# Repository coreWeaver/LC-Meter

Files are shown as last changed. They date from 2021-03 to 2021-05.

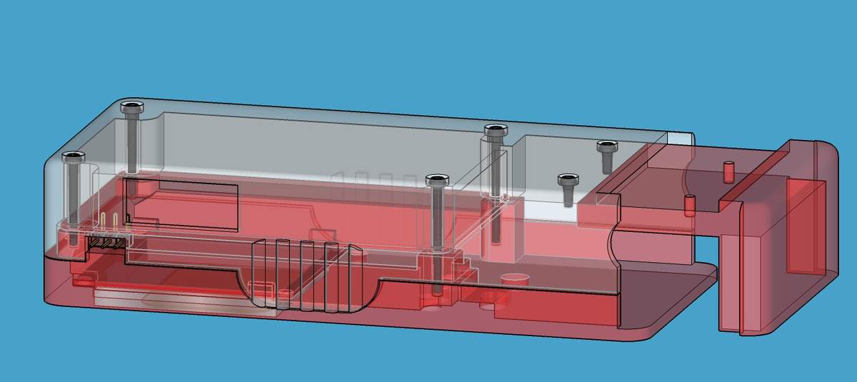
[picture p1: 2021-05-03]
LC Meter v1.0/4a. LC Meter Case - STL (UPDATED)/UPDATED LC Meter Case - transparent.JPG

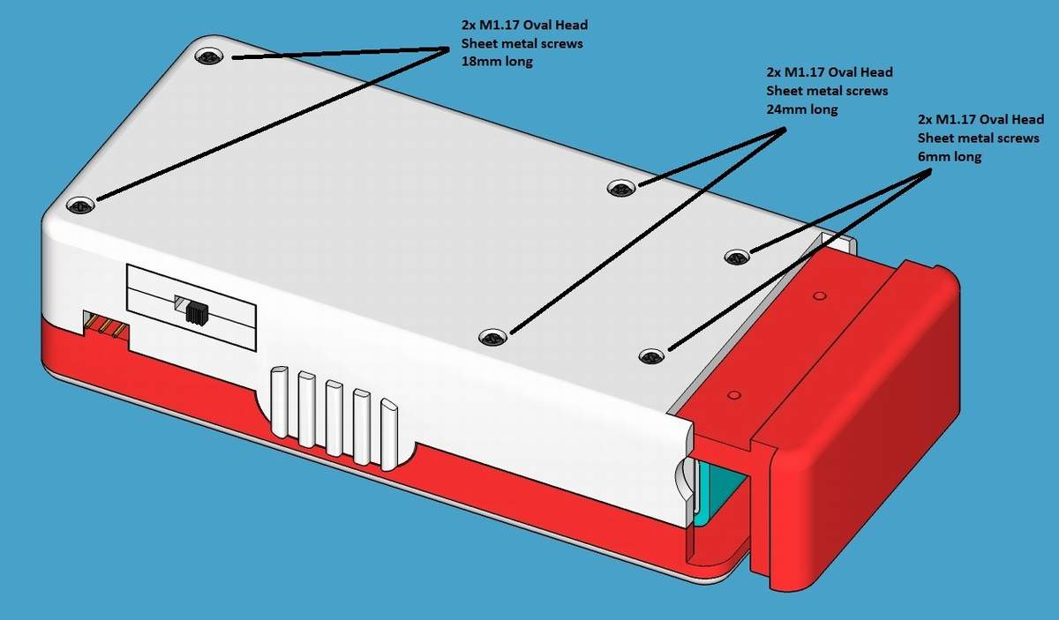
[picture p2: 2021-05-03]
LC Meter v1.0/4a. LC Meter Case - STL (UPDATED)/UPDATED LC Meter Case.JPG

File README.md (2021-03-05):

# LC-Meter
Open Source LC-Meter. All documentation included.

This LC Meter Project is open source. All the documentation both hardware and software is provided without any warranty.
If you build one I would be glad to get a picture of your finished device. 
Subscribe to my Youtube channel and post your comments and questions about this project in the comment section of the series.

The video series is a full tutorial on how it works, how to build it and how to test it.
You can watch it here: https://www.youtube.com/watch?v=KhJiE4gL5T4   (part 1)

About this project:

This design is based on Neil Hecht's idea. It uses an oscillator (LM311) to generate a frequency which can be modified by adding a capacitance or an inductance on the measuring terminals. The frequency is monitored by the microcontroller (ATMEGA328p) and all the math is then performed to extract the value of the added capacitance or inductance.
The value is then adjusted in engineering units and showed on a graphical display.

The PCB is designed using through-hole-terminal components only so it is very easy to solder. There is place for improvements in the schematic, just like I explained in the part 2 of the series (watch here: https://www.youtube.com/watch?v=jytJJjer8_M ).

This project can be improved. A second version would probably include these changes: 

	- make use of a rechargeable Li Ion battery
	- add a usb connector on board 
	- add charging circuitry for the battery
	- add UART - USB translation circuitry on board
	- add a voltage step up to boost the battery voltage to 5V
	- increase the frequency of the AVR

The LC Meter PC application was written in C# and it's very useful when a lot of measurements have to be done. It includes a catalog function for the measured components and a UART logging function for debug purposes.

The firmware for the microcontroller is written in BASCOM. The source files are present also and you can modify them or port to other language if you wish. There is a readme file in the Firmware folder with the FUSES Configuration for the AVR if you decide to use the precompiled firmware.

coreWeaver - ioCONNECTED / Mar. 2021

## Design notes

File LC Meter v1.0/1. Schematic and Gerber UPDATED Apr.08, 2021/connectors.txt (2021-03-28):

LC Meter
coreWeaver/ ioCONNECTED 

Measuring connectors:

Female connectors (for the case) - Spring-mounted socket:

https://www.reichelt.de/de/en/2-0-mm-miniature-socket-red-mbi-1-rt-p11294.html?search=mbi&&r=1

and

https://www.reichelt.de/de/en/miniature-socket--2-mm-black-mbi-1-sw-p11295.html?&trstct=vrt_pdn&nbc=1

The measuring leads:

https://www.reichelt.de/de/en/2-0-mm-mvl-2-50-measuring-lead-red-mvl-2-50-rt-p106057.html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

and

https://www.reichelt.de/de/en/2-0-mm-mvl-2-50-measuring-lead-black-mvl-2-50-sw-p106056.html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

The alligator clips for these leads:

https://www.reichelt.de/de/en/miniature-alligator-clip-2-mm-socket-tin-plated-red-ma-1-s-rt-p130862.html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

and

https://www.reichelt.de/de/en/miniature-alligator-clip-2-mm-socket-tin-plated-black-ma-1-s-sw-p130861.html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

PCB Probes which will fit on these leads:

https://www.reichelt.de/de/en/test-probe--2-mm-red-mps-1-rt-p13109.html?&trstct=pol_14&nbc=1

and

https://www.reichelt.de/de/en/test-probe--2-mm-black-mps-1-sw-p13110.html?&trstct=vrt_pdn&nbc=1

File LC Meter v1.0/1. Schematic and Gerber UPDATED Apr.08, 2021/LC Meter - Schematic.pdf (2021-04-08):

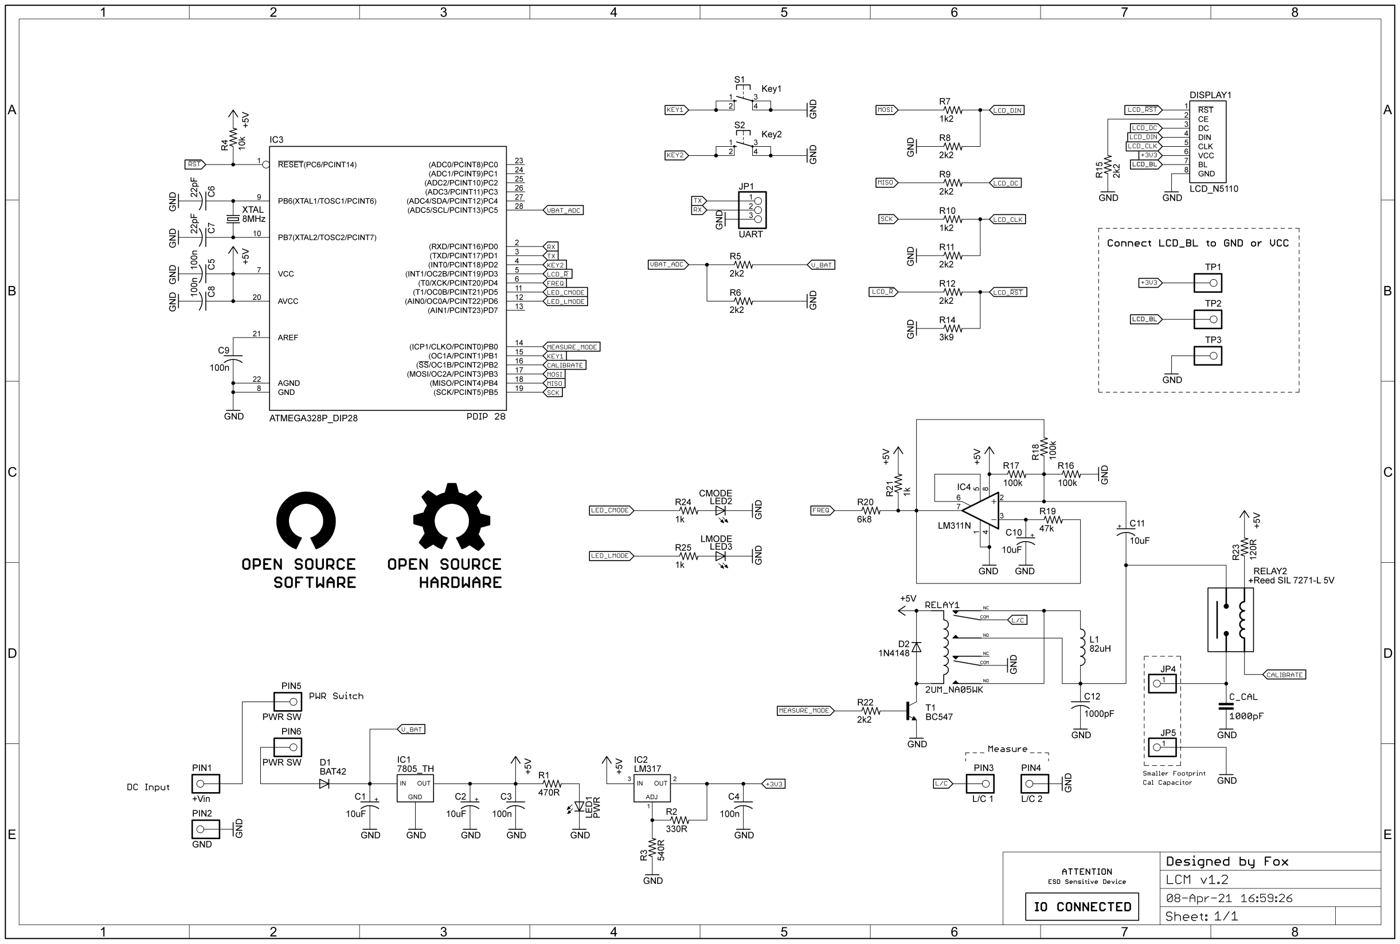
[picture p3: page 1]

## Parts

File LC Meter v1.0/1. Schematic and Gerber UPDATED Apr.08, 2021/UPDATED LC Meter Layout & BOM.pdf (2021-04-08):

LC Meter – Layout (UPDATED: Apr. 08, 2021)

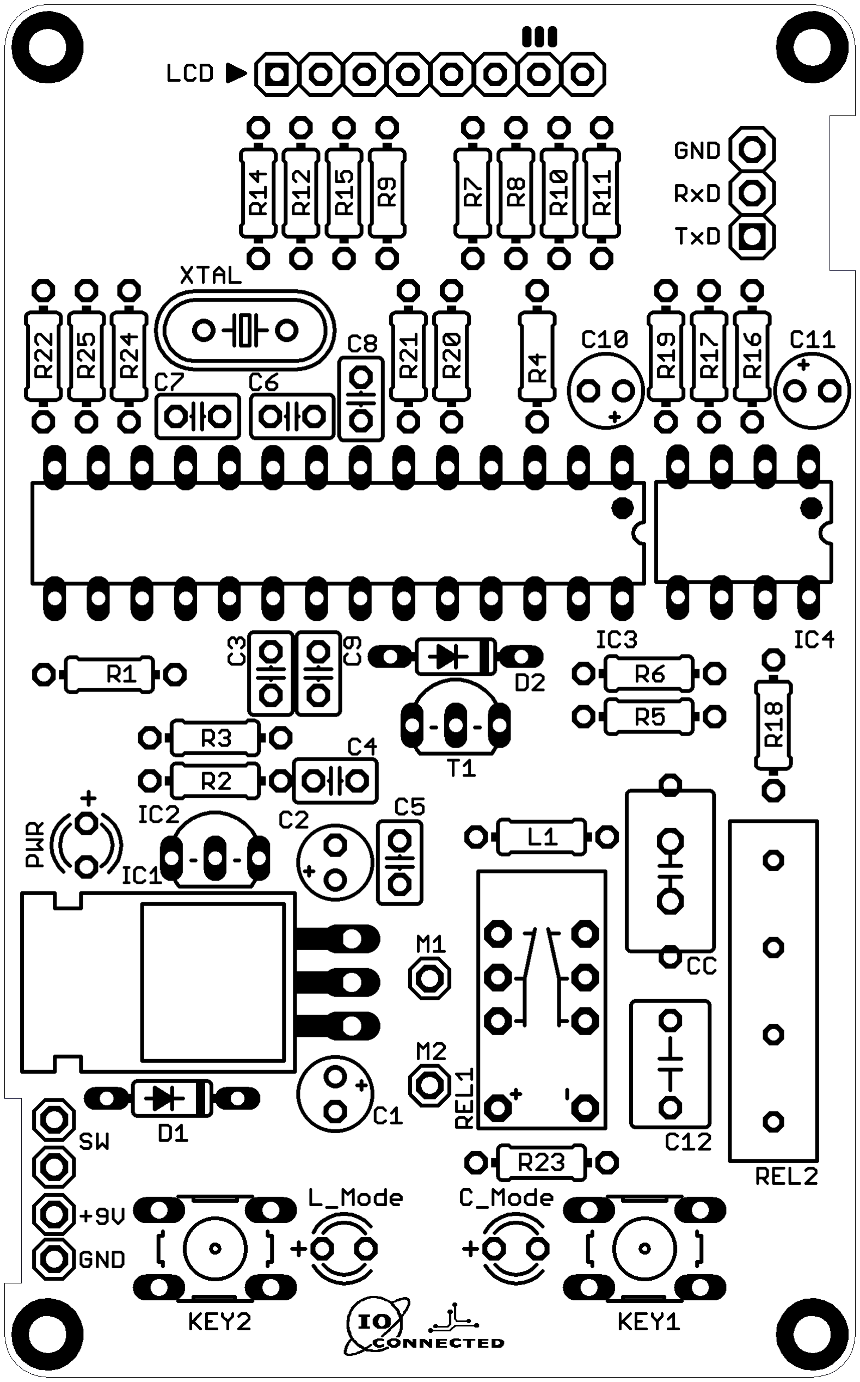
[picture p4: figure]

LC Meter Layout & BOM (UPDATED: Apr. 08, 2021) | 1

## LC Meter – BOM

Qty Value | Package | Parts
1 | 7805 | TO220 | IC1
1 | LM317 | TO92 | IC2
1 | ATMEGA328P | DIP28 | IC3
1 | LM311N | DIP8 | IC4
1 | 8MHz | HC49U-V | XTAL
3 | 1k | R-US_0204/7 | R21, R24, R25
1 | 470R | R-US_0204/7 | R1
1 | 330R | R-US_0204/7 | R2
1 | 540R | R-US_0204/7 | R3
1 | 10k | R-US_0204/7 | R4
2 | 1k2 | R-US_0204/7 | R7, R10
8 | 2k2 | R-US_0204/7 | R5, R6, R8, R9, R11, R12, R15, R22
1 | 3k9 | R-US_0204/7 | R14
1 | 6k8 | R-US_0204/7 | R20
1 | 120R | R-US_0204/7 | R23
3 | 100k | R-US_0204/7 | R16, R17, R18
1 | 47k | R-US_0204/7 | R19
4 | 10uF | CPOL-USE2-4 | C1, C2, C10, C11
2 | 22pF | C-US025-025X050 | C6, C7
5 | 100n | C-US025-025X050 | C3, C4, C5, C8, C9
1 | 1000pF | C-US050-045X075 | C12
1 | 1000pF | C-11.5X4.5 | C_CAL
1 | 82uH | L-US0204/7 | L1
1 | BAT42 | 1N4148DO35-7 | D1
1 | 1N4148 | 1N4148DO35-7 | D2
1 | BC547 | TRANSISTOR_NPN | T1
1 | PWR | LED_3MM | LED1
1 | CMODE | LED_3MM | LED2
1 | LMODE | LED_3MM | LED3
1 | 2UM_NA05WK | RELAY_2UMNA05WK | RELAY1
1 | Reed SIL 7271-L 5V | REED_RELAY | RELAY2
1 | Key1 | 10-XX | S1
1 | Key2 | 10-XX | S2
1 | UART | PINHD-1X03_2.54-S | JP1
1 | LCD_N5110_HEADER | PINHD-1X08_2.54-S | LCD Header*

*There are many different Breakouts for the Nokia's 5110 (3310) LCD. Make sure it has the following pinout, before buying:
1 – RST
2 – CE
3 – DC
4 – DIN
5 – CLK
6 – VCC
7 – Backlight
8 – GND

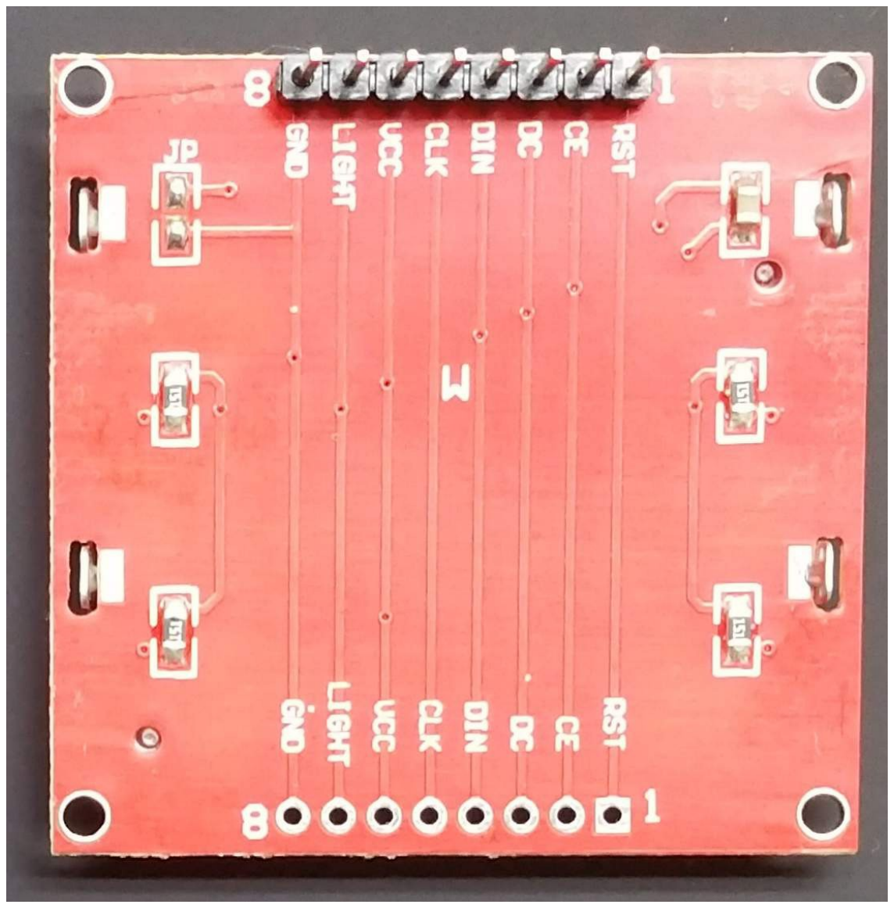
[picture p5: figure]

backside of the LCD

In 4 cases out of 5 the pin7 (Backlight) needs to be connected to VCC. However I also found one LCD with the exact pinout but with PIN7 (BL) connected to GND. That's why I included testpads on the PCB.

If your LCD's Backlight needs to be connected to GND, short these two pads (mid + right):

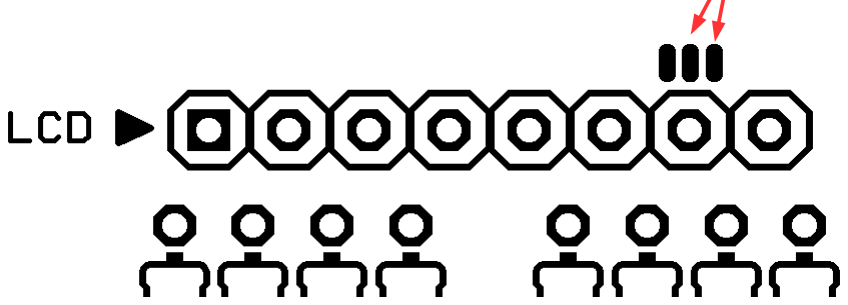
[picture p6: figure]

If the LCD's Backlight pin needs to be connected to VCC, short these two pads (mid + left):

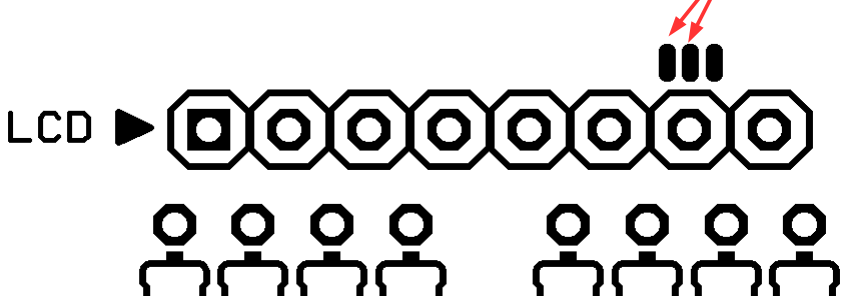
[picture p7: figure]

My special thanks to Mike Doty from "Hackaday" who discovered some of the errors in the original documentation, and helped me improve the LC-Meter's case.
Thanks Mike !

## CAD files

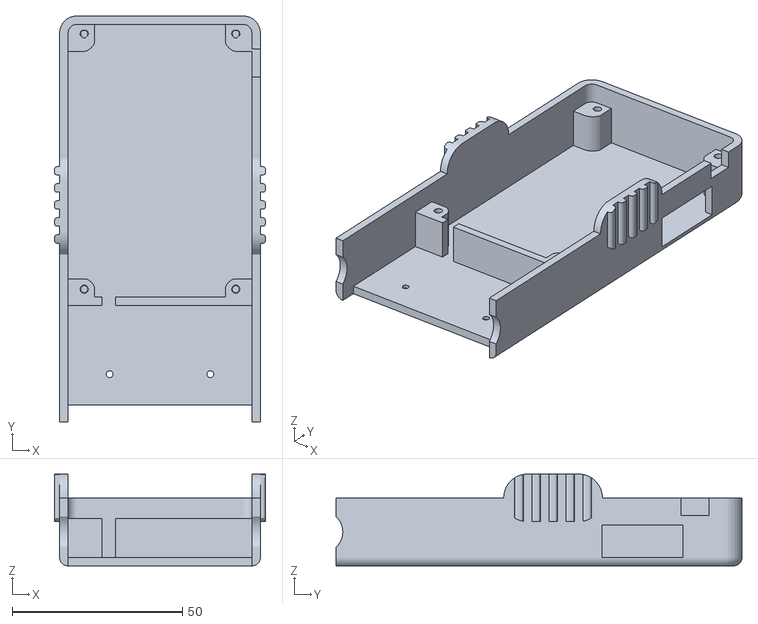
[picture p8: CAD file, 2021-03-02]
LC Meter v1.0/4. LC Meter Case - STL/w1.stl
62.0 x 119.2 x 27.0

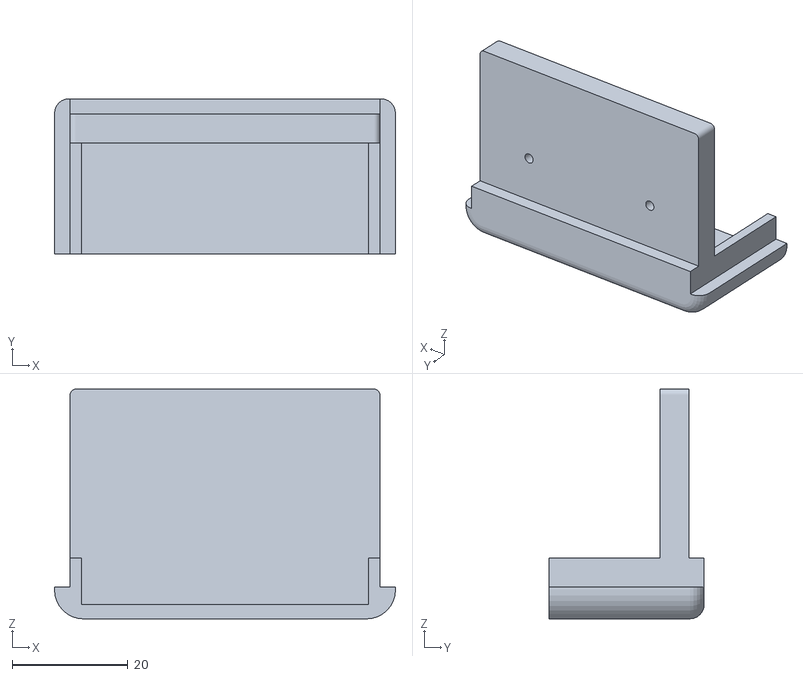
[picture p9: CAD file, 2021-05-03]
LC Meter v1.0/4a. LC Meter Case - STL (UPDATED)/LC Meter Updated Case (1.6mm PCB)/new_battery_cover (red_filament).stl
59.0 x 26.9 x 39.8

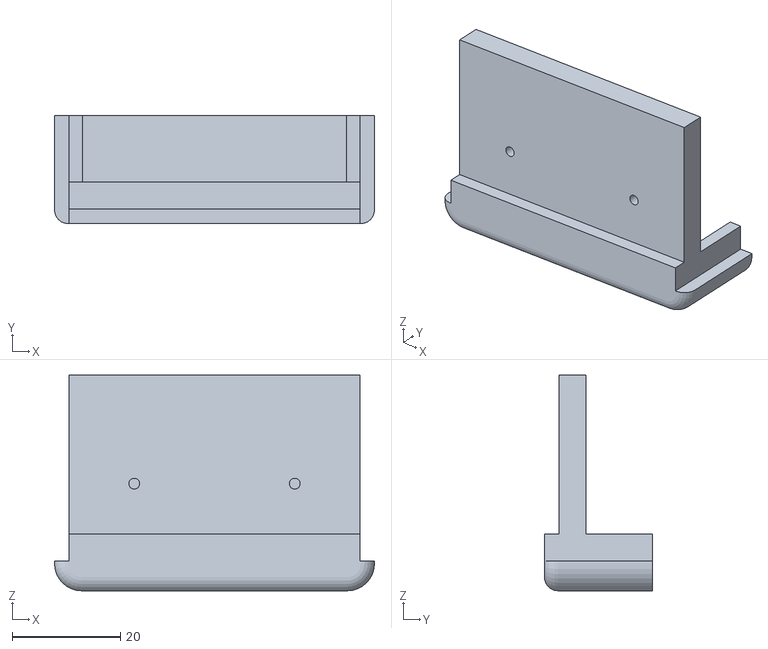
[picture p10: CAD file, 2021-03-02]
LC Meter v1.0/4. LC Meter Case - STL/r2.stl
59.0 x 20.0 x 39.8

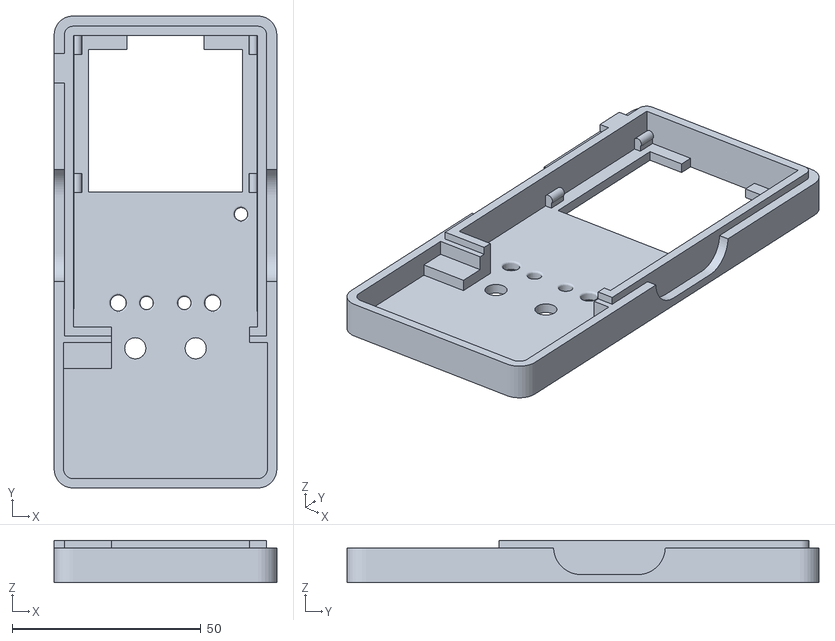
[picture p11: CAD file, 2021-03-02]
LC Meter v1.0/4. LC Meter Case - STL/r1.stl
59.0 x 125.0 x 11.3

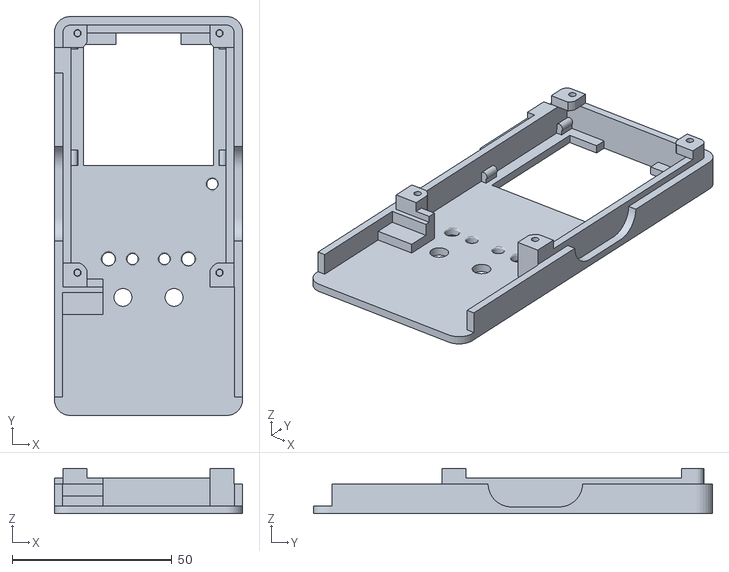
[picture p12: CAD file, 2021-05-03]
LC Meter v1.0/4a. LC Meter Case - STL (UPDATED)/LC Meter Updated Case (1.6mm PCB)/new_middle_section (red_filament).stl
59.0 x 125.0 x 14.3

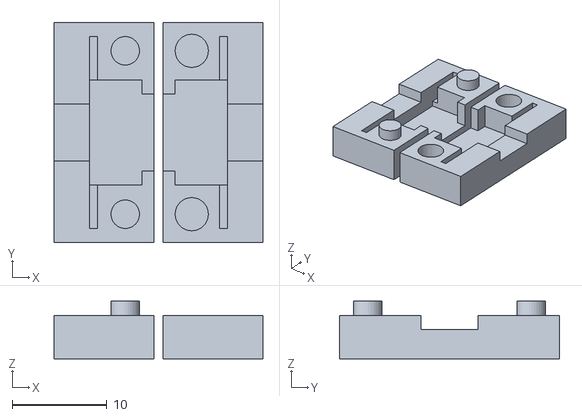
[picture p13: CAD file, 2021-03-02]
LC Meter v1.0/4a. LC Meter Case - STL (UPDATED)/LC Meter Updated Case (1.6mm PCB)/switch_enclosure (white_filament).stl
22.0 x 23.2 x 6.10

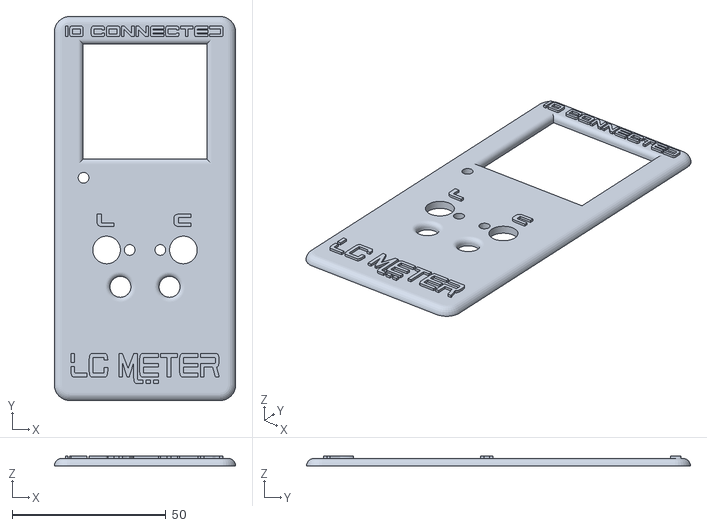
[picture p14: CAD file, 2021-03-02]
LC Meter v1.0/4a. LC Meter Case - STL (UPDATED)/LC Meter Updated Case (1.6mm PCB)/top_side (white_filament).stl
59.0 x 125.0 x 3.25

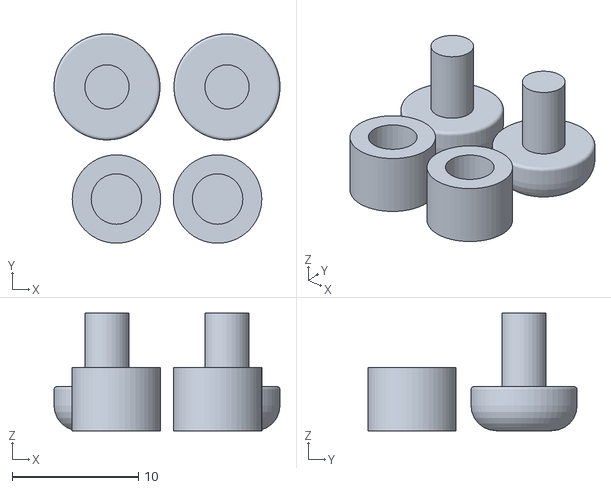
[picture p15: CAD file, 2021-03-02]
LC Meter v1.0/4a. LC Meter Case - STL (UPDATED)/LC Meter Updated Case (1mm PCB)/buttons_caps (red_filament).stl
17.9 x 16.6 x 9.30

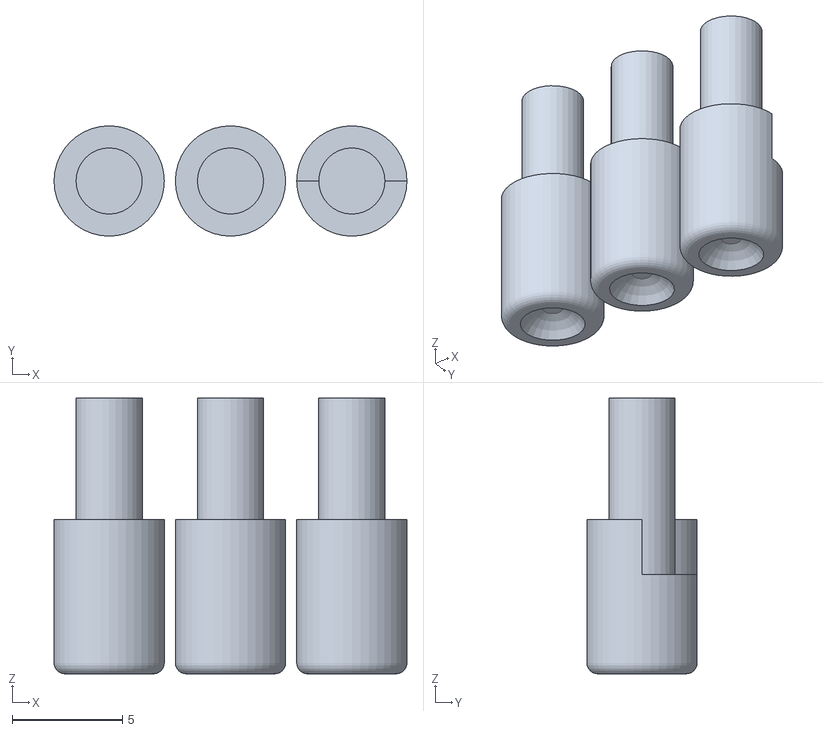
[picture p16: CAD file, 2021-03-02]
LC Meter v1.0/4a. LC Meter Case - STL (UPDATED)/LC Meter Updated Case (1.6mm PCB)/light_rods (transparent_filament).stl
16.0 x 5.00 x 12.5

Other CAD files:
LC Meter v1.0/4a. LC Meter Case - STL (UPDATED)/LC Meter Updated Case (1mm PCB)/new_bottom_section_1mmpcb (white_filament).stl
LC Meter v1.0/4a. LC Meter Case - STL (UPDATED)/LC Meter Updated Case (1.6mm PCB)/new_bottom_section_1.6mmpcb (white_filament).stl

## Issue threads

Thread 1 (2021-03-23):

BOM Question

ObiWanCanOweMe, 2021-03-23:
Hi,

I'm very new to this sort of electronics work but excited to take a crack at this project. I'm trying to source all the components but am having some difficulty in being certain I get the proper ones. Would it be possible to get a list of part/item numbers from one or more vendors (like mouser,com for example). That would help me out TREMENDOUSLY.

coreWeaver, 2021-03-28:
Hi,

I've updated the "LC Meter Layout & BOM.pdf" located in the "1. Schematic and Gerber" folder. Tell me if you find all the necessary answers there or if you still have a specific part which you can't find.

ObiWanCanOweMe, 2021-04-29:
Thanks for that but I'm still having some issues figuring out the right parts. For example, the BOM doesn't specify the voltage for the LED's. A list with manufacturer or vendor part numbers would be EXTREMELY helpful. I'm not in any rush so if that is something you can do I'd greatly appreciate it whenever you can get to it.

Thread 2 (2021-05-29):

BOM clarifications

rpavlik, 2021-05-29:
I'm finally getting around to putting together the parts order for the board, and I have some questions.

- What loading capacitance for the crystal?
- 5% resistors OK for all?
- 20% capacitors OK for all except the calibration one, right? I assume that should be a tighter tolerance plastic cap.

rpavlik, 2021-05-29:
Ahh, right so I see the 22pF caps next to the crystal so I picked a 20pF crystal, hopefully that's ok. I'll post the full order before I place it

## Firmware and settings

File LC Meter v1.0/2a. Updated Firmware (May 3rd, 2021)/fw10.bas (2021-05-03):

'--------------------------------------------------------------------------------------------------------
'                         LC Meter Firmware
'      June 2020 - coreWeaver / ioCONNECTED
'--------------------------------------------------------------------------------------------------------


' Copyright <2020> <coreWeaver / ioCONNECTED>

' Permission is hereby granted, free of charge,
' to any person obtaining a copy of this software and associated documentation files (the "Software"),
' to deal in the Software without restriction, including without limitation the rights to use,
' copy, modify, merge, publish, distribute, sublicense, and/or sell copies of the Software,
' and to permit persons to whom the Software is furnished to do so, subject to the following conditions:

' The above copyright notice and this permission notice shall be included in all copies or
' substantial portions of the Software.

' The Software Is Provided "AS IS" , Without Warranty Of Any Kind , Express Or Implied ,
' Including But Not Limited To The Warranties Of Merchantability , Fitness For A Particular Purpose
' And Noninfringement. In No Event Shall The Authors Or Copyright Holders Be Liable For Any Claim ,
' Damages Or Other Liability , Whether In An Action Of Contract , Tort Or Otherwise , Arising From ,
' Out Of Or In Connection With The Software Or The Use Or Other Dealings In The Software.

'--------------------------------------------------------------------------------------------------------
'--------------------------------------------------------------------------------------------------------



$regfile = "m328pdef.dat"
$crystal = 8000000
$baud = 19200
$hwstack = 256
$swstack = 256
$framesize = 256


' UART Config
Config Com1 = 19200 , Synchrone = 0 , Parity = None , Stopbits = 1 , Databits = 8 , Clockpol = 0
Open "com1:" For Binary As #1
Config Serialin0 = Buffered , Size = 30 , Bytematch = All

' Use ADC's Channel_5 to measure VBAT
Config Adc = Single , Prescaler = Auto , Reference = Avcc
Start Adc

'using watchdog for SW RST
Config Watchdog = 128                                       'ovf after 128ms and resets the uC

' Timers Usage:
' Timer0 is used to count the incoming pulses on T0 (PD4)
' Timer1 is used to generate a 1sec time interval for frequency measurement
' Timer2 is used to raise a flag (Ok_to_read_Vbat) every 4 seconds


' Frequency Counter from 4 Hz to 5 MHz

' Timer1 Config (1 Second time interval)
On Timer1 Timer1_routine
Tccr1a = &B00000000
Tccr1b = &B00000101                                         ' Prescaller 1024

Timsk2 = &B00000001                                         ' Interrupt for Timer 2 active
Timsk1 = &B00000001                                         ' Interrupt for Timer 1 active
Timsk0 = &B00000001                                         ' Interrupt for Timer 0 active

Sreg = &B10000000                                           ' Global Interrupts on

Timer1 = 57644
' this value was found by using a resonator (4MHz)
' and adjusting the value of timer1 to match the 4000000 Hz output


' Timer0 Config
On Timer0 Timer0_routine
Tccr0 = &B00000111                                          ' Count external Signals on Rising Edge


' Timer2 Config (read and display the battery voltage every 4 seconds)
On Timer2 Timer2_routine
Tccr2a = &B00000000
Tccr2b = &B00000101                                         ' Prescaller 1024
Timer2 = 178                                                ' OVF each 10 ms
' count 4 seconds in INT routine then raise Ok_to_read_vbat Flag


Enable Interrupts

$lib "glcd-Nokia3310.lib"

' LCD Rst & Cs1 are not used
Config Graphlcd = 128x64sed , Rst = Portd.3 , A0 = Portb.4 , Si = Portb.3 , Sclk = Portb.5

'Const Negative_lcd = 1                                      ' Invert screen
Const Rotate_lcd = 0

' LEDs
Config Portd.5 = Output
Blue_led Alias Portd.5
Reset Blue_led

Config Portd.6 = Output
Red_led Alias Portd.6
Reset Red_led

' Keys
Config Pinb.1 = Input
Key1 Alias Pinb.1
Portb.1 = 1


Config Pind.2 = Input
Key2 Alias Pind.2
Portd.2 = 1

' Reed Relay (adds Calibration Capacitor)
Config Portb.2 = Output
Calibrate Alias Portb.2
Set Calibrate                                               ' disconnect Ccal

' Measure Mode
' double relay
' SET   (Normally Open)  >> C Mode
' RESET (Normally Close) >> L Mode
Config Portb.0 = Output
Measure_mode Alias Portb.0
Reset Measure_mode

Dim Overflowed As Long
Dim Pulses As Long
Dim I As Byte , J As Byte , K As Byte
Dim Tim2var As Integer

Const Pi = 3.141592653589793
Const 2pi = 6.283185307179586
Const Ccal = 0.000000001006                                 ' Farads or 1006 [pF]

Const Milli = 0.001
Const Micro = 0.000001
Const Nano = 0.000000001
Const Pico = 0.000000000001

Const Cr = &H0D
Const Lf = &H0A



Dim F1 As Single                                            ' Oscillator's base freq. (Ccal, C_det & L_det disconnected)
Dim F2 As Single                                            ' Calibration freq. (Ccal connected, C_det & L_det disconnected)
Dim F3 As Single                                            ' Ccal disconnected, C_det connected, L_det disconnected
Dim F4 As Single                                            ' Ccal disconnected, C_det disconnected, L_det disconnected

Dim Dvar1 As Single
Dim Dvar2 As Single

Dim Svar1 As Single

Dim C_measured As Single
Dim L_measured As Single

Dim Scaled_val As Single
Dim New_str_value As String * 20

Dim Adcval As Word
Dim Vbat As Single
Dim Vbat_str As String * 5

Dim X As Byte

Dim Lbat_pic As Bit
Reset Lbat_pic

Dim Ok_to_read_vbat As Bit
Reset Ok_to_read_vbat

Dim A As Byte
Dim Rx_buffer As String * 30 , Rx_string As String * 30
Dim Full_buffer As Bit , Rx_flag As Bit
Reset Full_buffer : Reset Rx_flag

Declare Sub Read_vbat
Declare Sub Calibration
Declare Sub Measure_c
Declare Sub Measure_l
Declare Sub Convert(value As Single)

' Initialize LCD
Initlcd
Glcdcmd 33 : Glcdcmd 200                                    ' Normal Contrast
Cls

' select Capacity Mode
Set Measure_mode

Print "LC-Meter.ioConnected.OK"

Setfont Newfont6x8
Showpic 1 , 1 , Splash
Waitms 1000
Cls
Lcdat 3 , 10 , "ioConnected"
Lcdat 4 , 52 , "2020"
Waitms 2000

Print "Ready"
Waitms 500

Call Calibration
Print
Print

Do
   If Ok_to_read_vbat = 1 Then Call Read_vbat
   If Key1 = 0 Then
      Print "Measuring Capacitance >>>>"
      Waitms 500
      If Key2 = 0 Then
         Call Calibration
      Else
         Call Measure_c
      End If
   End If


   If Key2 = 0 Then
      Print "Measuring Inductance >>>>"
      Waitms 500
      If Key1 = 0 Then
         Call Calibration
      Else
         Call Measure_l
      End If
   End If

   If Rx_flag = 1 Then
      Select Case Rx_string
         Case "rst!":
            Start Watchdog
      End Select
   End If



Loop
End
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
